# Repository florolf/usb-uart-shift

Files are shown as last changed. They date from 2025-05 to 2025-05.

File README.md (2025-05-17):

# usb-uart-shift

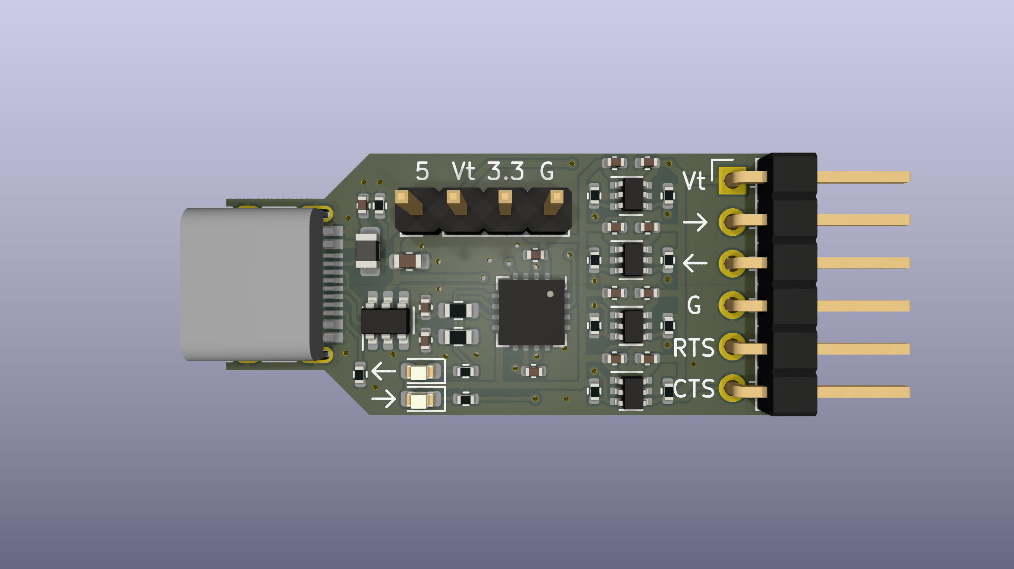
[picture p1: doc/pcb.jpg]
3D render of the PCB


This is an FT230X-based USB-UART adapter with built-in level shifting. This
allows talking to targets using different I/O voltage levels (1.8V to 5V), but
it's especially useful to avoid backpowering a target through the TX line.

This board can be assembled by JLCPCB PCBA for about $5 each, see the `fab/`
directory for Gerber/BOM/CPL data.

## Usage

The I/Os on the right-angle header (J1) are:

 * `->` (output, UART TX from the perspective of the adapter)
 * `<-` (input, RX)
 * `G` (GND)
 * `RTS` (output)
 * `CTS` (input)

The pins are arranged such that a 4-pin receptacle on the target is sufficient
when designing specifically for interfacing with this adapter if flow control
is not needed.

Level-shifting is configured through the 4-pin header (J2). When the I/O
reference voltage is available from the target it is recommended to connect it
to `Vt` and leave J2 open.

Alternatively, you can connect a jumper between `3.3` and `Vt` or `5` and `Vt`
on J2 to set the I/O voltage to 3.3V or 5V (strictly speaking USB VBUS),
respectively. However, in this case we cannot detect an unpowered target and
the usual backpowering considerations will apply. You can also just connect a
lab power supply to `Vt` and `G`.

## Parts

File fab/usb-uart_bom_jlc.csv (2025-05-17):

Designator | Footprint | SPN
C11,C12 | C_0402_1005Metric | C1567
C8 | C_0402_1005Metric | C15195
C2,C3,C4,C5,C6,C7,C9,C10,C13,C14 | C_0402_1005Metric | C307331
C1 | C_0603_1608Metric | C19666
D1 | LED_0603_1608Metric | C2286
D2 | LED_0603_1608Metric | C72038
FB1 | L_0805_2012Metric | C1015
J2 | PinHeader_1x04_P2.54mm_Vertical | C6332197
J3 | PinHeader_1x06_P2.54mm_Horizontal | C492414
J1 | USB_C_Receptacle_HRO_TYPE-C-31-M-12 | C165948
R3,R4 | R_0603_1608Metric | C25190
R5,R6 | R_0402_1005Metric | C25862
R1,R2 | R_0402_1005Metric | C25905
R7,R8,R9,R10,R11,R12,R13,R14 | R_0402_1005Metric | C25744
U2 | QFN-16-1EP_4x4mm_P0.65mm_EP2.1x2.1mm | C128629
U3,U4,U5,U6 | SOT-363_SC-70-6 | C9382
U1 | SOT-23-6 | C85364

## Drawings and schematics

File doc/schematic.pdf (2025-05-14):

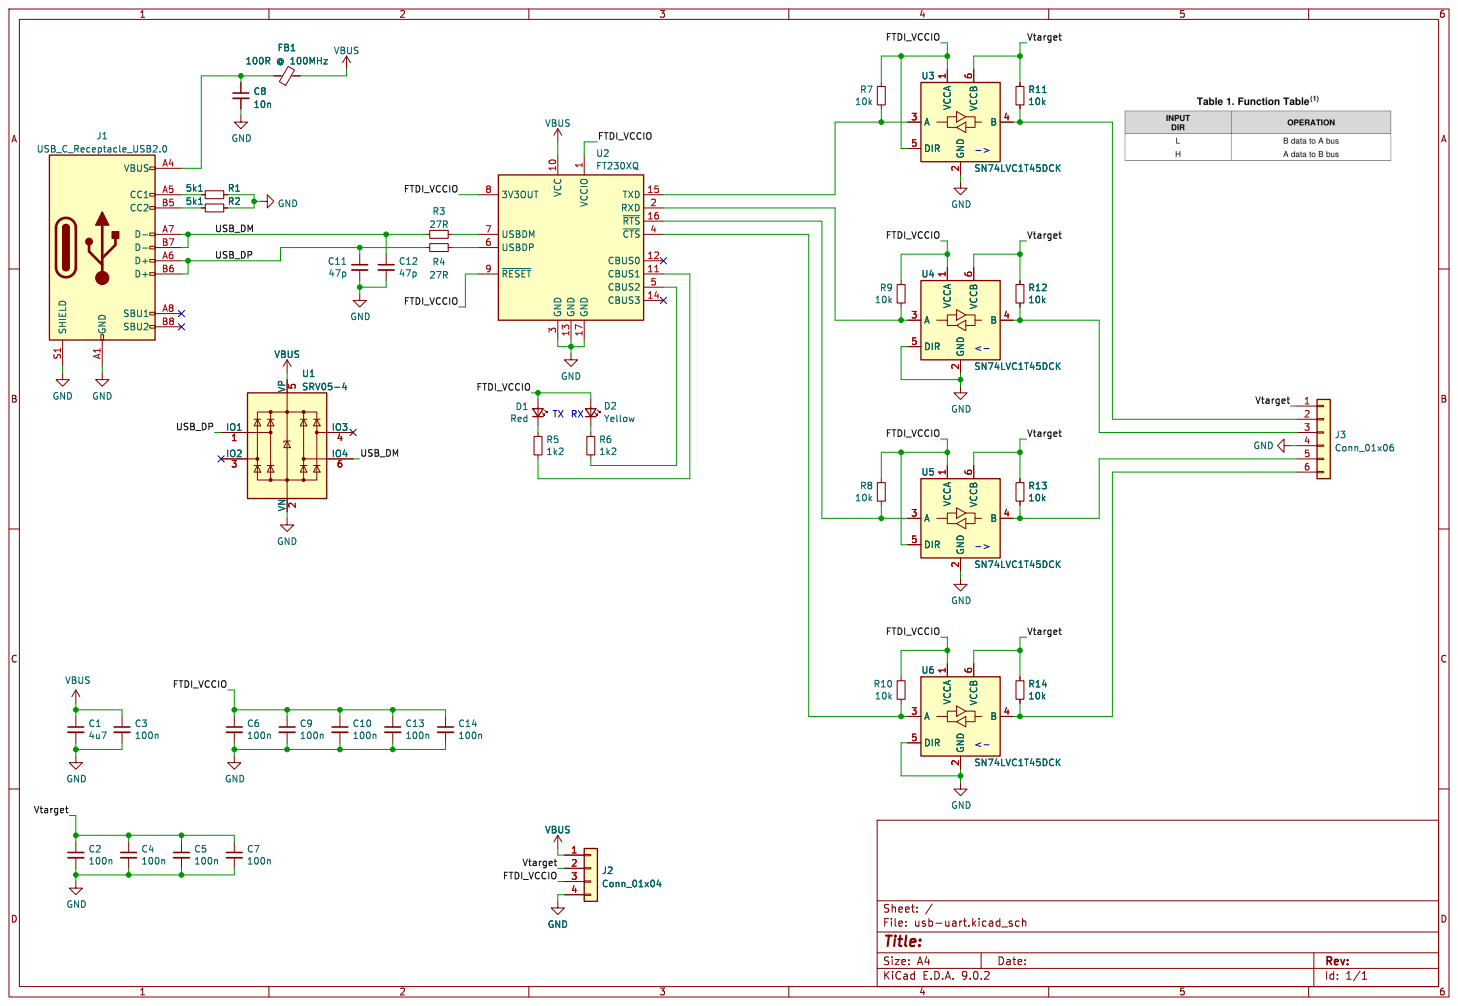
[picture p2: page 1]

Id: 1/1 Title: File: usb-uart.kicad_sch Sheet: /

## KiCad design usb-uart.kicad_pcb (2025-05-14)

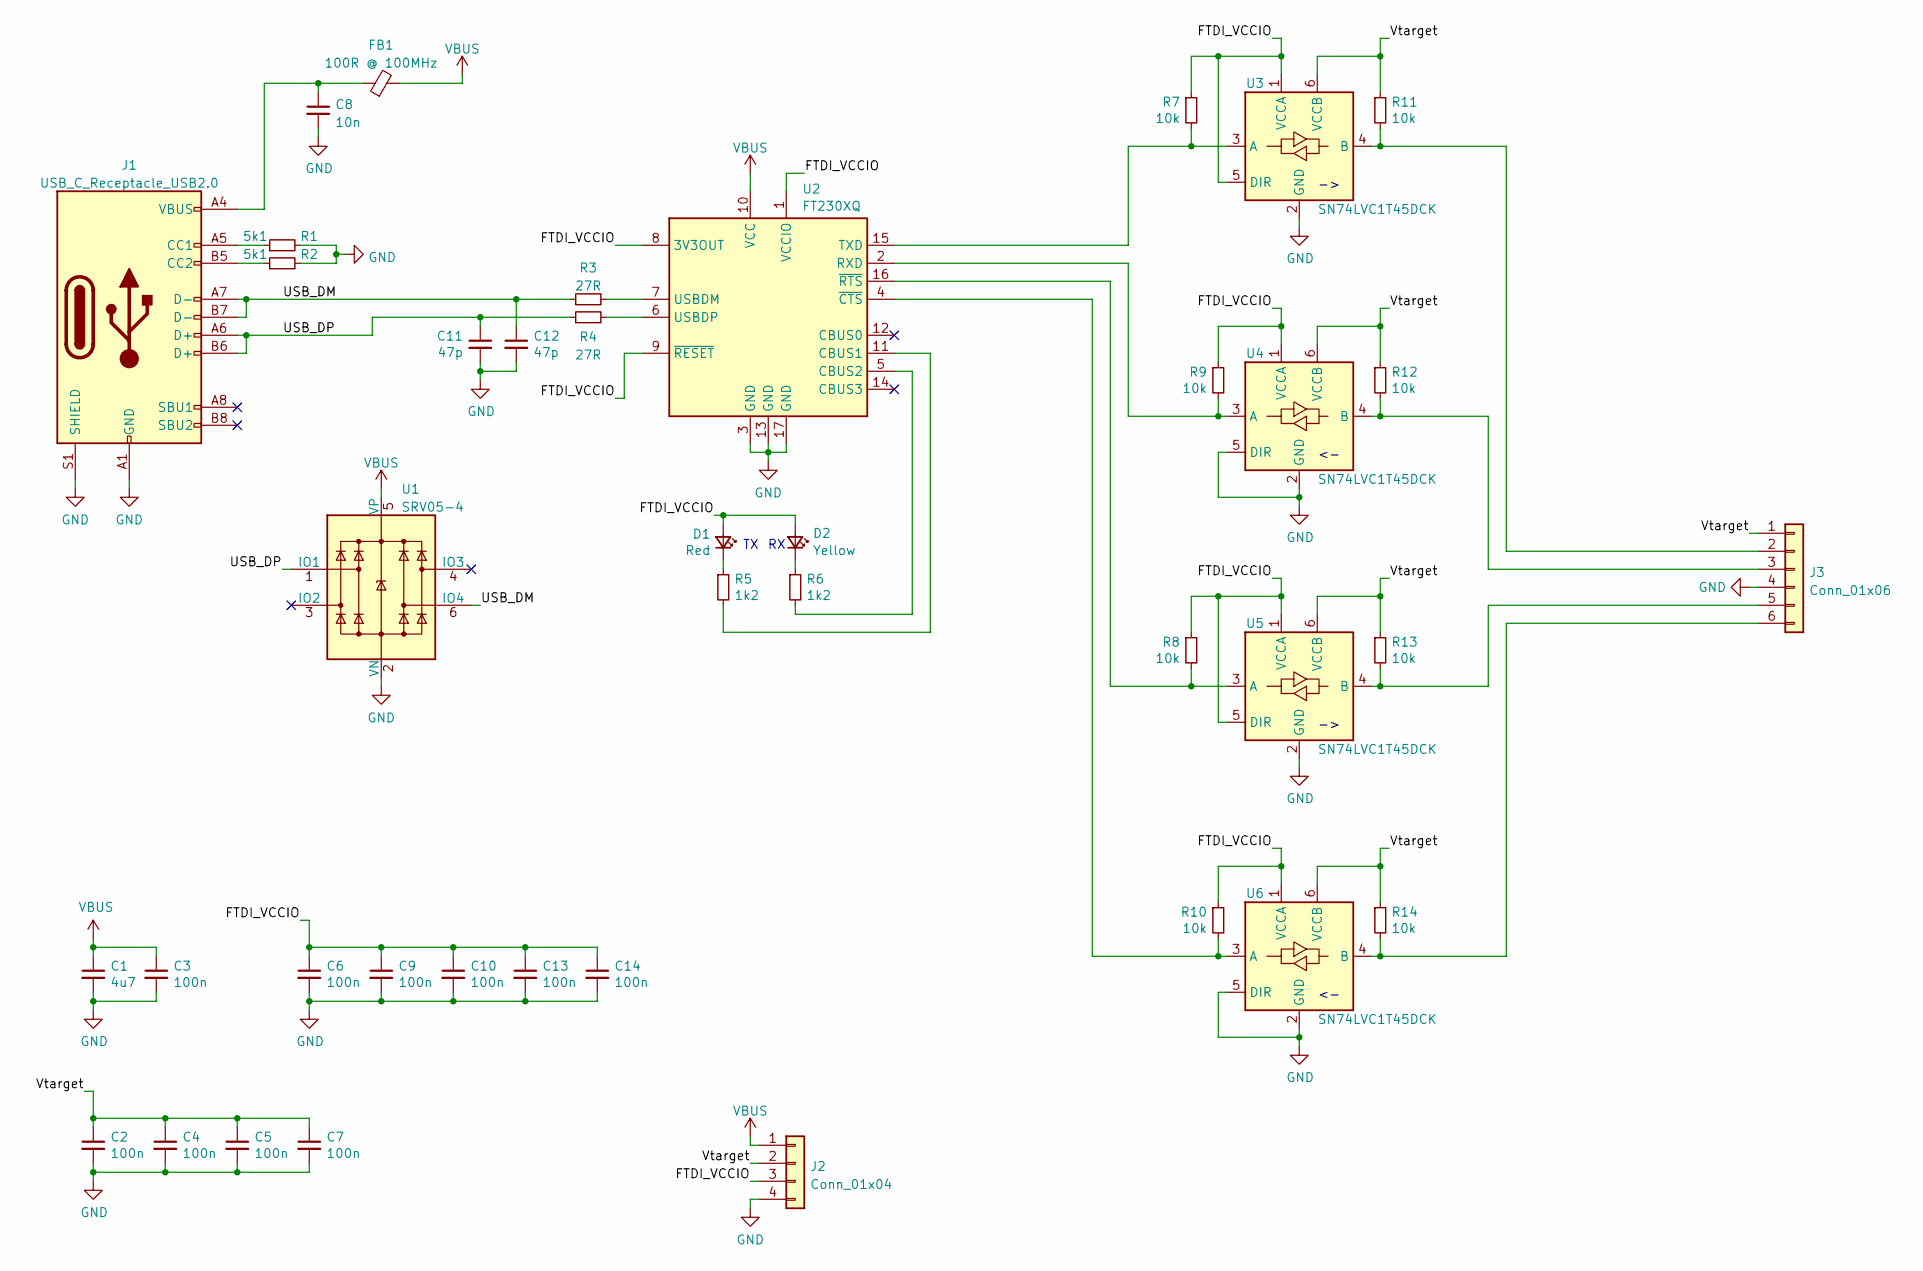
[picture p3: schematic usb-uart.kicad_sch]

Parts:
C1: 4u7; C_0603_1608Metric; MPN CL10A475KO8NNNC; JLCPCB C19666
C2, C3, C4, C5, C6, C7, C9, C10, C13, C14: 100n; C_0402_1005Metric; MPN CL05B104KB54PNC; JLCPCB C307331
C8: 10n; C_0402_1005Metric; JLCPCB C15195
C11, C12: 47p; C_0402_1005Metric; MPN 0402CG470J500NT; JLCPCB C1567
D1: Red; LED_0603_1608Metric; JLCPCB C2286
D2: Yellow; LED_0603_1608Metric; JLCPCB C72038
FB1: 100R @ 100MHz; L_0805_2012Metric; MPN GZ2012D101TF; JLCPCB C1015
J1: USB_C_Receptacle_USB2.0; USB_C_Receptacle_HRO_TYPE-C-31-M-12; MPN TYPE-C-31-M-12; JLCPCB C165948
J2: Conn_01x04; PinHeader_1x04_P2.54mm_Vertical; JLCPCB C6332197
J3: Conn_01x06; PinHeader_1x06_P2.54mm_Horizontal; JLCPCB C492414
R1, R2: 5k1; R_0402_1005Metric; MPN 0402WGF5101TCE; JLCPCB C25905
R3, R4: 27R; R_0603_1608Metric; JLCPCB C25190
R5, R6: 1k2; R_0402_1005Metric; JLCPCB C25862
R7, R8, R9, R10, R11, R12, R13, R14: 10k; R_0402_1005Metric; JLCPCB C25744
U1: SRV05-4; SOT-23-6; JLCPCB C85364
U2: FT230XQ; QFN-16-1EP_4x4mm_P0.65mm_EP2.1x2.1mm; MPN FT230XQ-R; JLCPCB C128629
U3, U4, U5, U6: SN74LVC1T45DCK; SOT-363_SC-70-6; MPN SN74LVC1T45DCKR; JLCPCB C9382

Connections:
/FTDI_VCCIO: C6.1, C9.1, C10.1, C13.1, C14.1, D1.2 (A), D2.2 (A), J2.3, R7.1, R8.1, R9.1, R10.1, U2.1 (VCCIO), U2.8 (3V3OUT), U2.9 (~RESET), U3.1 (VCCA), U3.5 (DIR), U4.1 (VCCA), U5.1 (VCCA), U5.5 (DIR), U6.1 (VCCA)
/USB_DM: C12.1, J1.A7 (D-), J1.B7 (D-), R3.1, U1.6 (IO4)
/USB_DP: C11.1, J1.A6 (D+), J1.B6 (D+), R4.1, U1.1 (IO1)
/Vtarget: C2.1, C4.1, C5.1, C7.1, J2.2, J3.1, R11.1, R12.1, R13.1, R14.1, U3.6 (VCCB), U4.6 (VCCB), U5.6 (VCCB), U6.6 (VCCB)
GND: C1.2, C2.2, C3.2, C4.2, C5.2, C6.2, C7.2, C8.2, C9.2, C10.2, C11.2, C12.2, C13.2, C14.2, J1.A1 (GND), J1.A12 (GND), J1.B1 (GND), J1.B12 (GND), J1.S1 (SHIELD), J2.4, J3.4, R1.2, R2.2, U1.2 (VN), U2.3 (GND), U2.13 (GND), U2.17 (GND), U3.2 (GND), U4.2 (GND), U4.5 (DIR), U5.2 (GND), U6.2 (GND), U6.5 (DIR)
unnamed: C8.1, FB1.1, J1.A4 (VBUS), J1.A9 (VBUS), J1.B4 (VBUS), J1.B9 (VBUS)
unnamed: D1.1 (K), R5.1
unnamed: D2.1 (K), R6.1
unnamed: J1.A5 (CC1), R1.1
unnamed: J1.B5 (CC2), R2.1
unnamed: J3.2, R11.2, U3.4 (B)
unnamed: J3.3, R12.2, U4.4 (B)
unnamed: J3.5, R13.2, U5.4 (B)
unnamed: J3.6, R14.2, U6.4 (B)
unnamed: R5.2, U2.11 (CBUS1)
unnamed: R6.2, U2.5 (CBUS2)
unnamed: R9.2, U2.2 (RXD), U4.3 (A)
unnamed: R7.2, U2.15 (TXD), U3.3 (A)
unnamed: R3.2, U2.7 (USBDM)
unnamed: R4.2, U2.6 (USBDP)
unnamed: R10.2, U2.4 (~CTS), U6.3 (A)
unnamed: R8.2, U2.16 (~RTS), U5.3 (A)
VBUS: C1.1, C3.1, FB1.2, J2.1, U1.5 (VP), U2.10 (VCC)

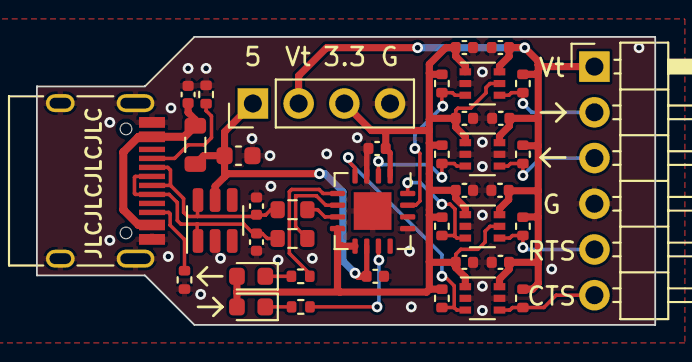
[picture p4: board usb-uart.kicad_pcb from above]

Board: 2 copper layers, 34.3 x 16.0 mm, 40 parts (0 on the bottom side), 23 nets.
